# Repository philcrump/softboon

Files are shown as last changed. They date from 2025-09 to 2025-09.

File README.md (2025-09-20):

# SoftBoon

A programmable soft-start board for the Boondocker Dishy Dualie, to ease current surge at start-up.

This project is in no way associated or affiliated with Boondock Energy, Inc.

## Implementation

Small PCB designed for retrofit into an existing project.

<p float="center">
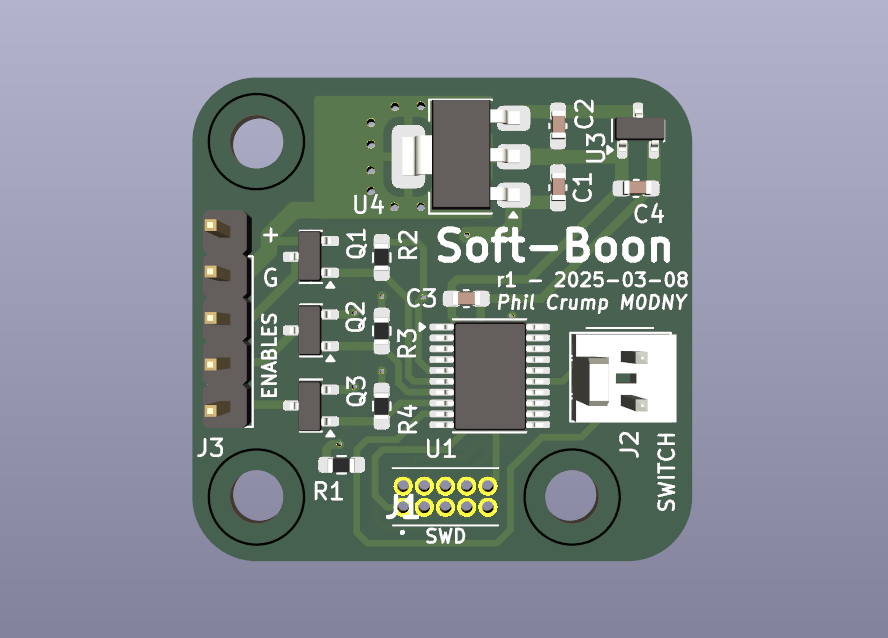
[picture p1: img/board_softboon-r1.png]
  
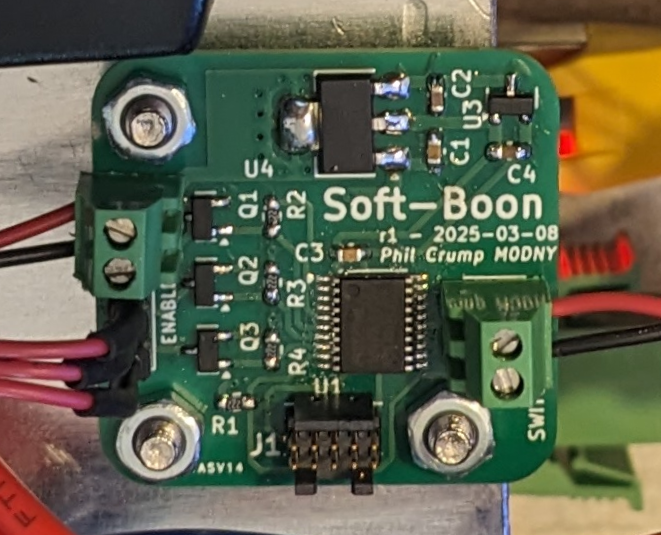
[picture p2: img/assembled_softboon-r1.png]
  
</p>

Schematic: [img/schematic_softboon-r1.pdf](img/schematic_softboon-r1.pdf)

Dual voltage regulators allow use of 7-35V on input (Boondocker is 10-30V).

An STM32F030K6 programmable microcontroller generates the timing logic as follows:

At initial power-on:
* DC-DC and all outputs off.

When the mechanical switch input is On (open)
* Wait 1 second
* Switch the DC-DC on.
* Wait 1 second
* Switch the Dishy PoE on (and Aux Output.)
* Wait 1 second
* Switch the Router PoE on.

When the mechanical switch is Off (closed)
* Immediately switch all outputs and DC-DC off.

### Board Connections

5-pin Header J3:
* "+" (Positive Supply): Recommended to be connected after Fuse and Diode arrangement on the input of the Boondocker to benefit from Reverse Polarity protection. Can tolerate 7-35V.
* "G" (Common/Ground): "Common" on the Dishy Dualie "Remote Shutdown" header.
* Enable 0: "Router Switch" on the Dishy Dualie "Remote Shutdown" header." Can tolerate 45V open, 500mA short.
* Enable 1: "DC-DC Switch" on the Dishy Dualie "Remote Shutdown" header." Can tolerate 45V open, 500mA short.
* Enable 2: "Dishy Switch" on the Dishy Dualie "Remote Shutdown" header." Can tolerate 45V open, 500mA short.

2-pin Header J2:
* Short pins to switch unit off (optional, leave disconnected for always-on). 3.3V @ 1.1mA when shorted.

### Firmware

Written in Rust using the Embassy Framework.

NB: Optimisation and LTO is required to fit the Flash of the microcontroller.

#### Inputs

* PA3 - Switch, 3.3V open, 1.5mA closed.

#### Outputs

* PA0 - Q1 Transistor - Router Switch
* PA1 - Q2 Transistor - DC-DC
* PA2 - Q3 Transistor - Dishy

## Authors

* Phil Crump <phil@philcrump.co.uk>

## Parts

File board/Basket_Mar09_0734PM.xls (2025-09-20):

SHOPPING BASKET
This is not an invoice
09-Mar-25 19:34:48
 | Mouser No | Mfr. No | Manufacturer | Customer No | Description | RoHS | Lifecycle | Order Qty. | Price (GBP) | Ext.: (GBP)
1 | 511-STM32F030F4P6 | STM32F030F4P6 | STMicroelectronics |  | ARM Microcontrollers - MCU Value-Line ARM MCU 16kB 48 MHz | RoHS Compliant |  | 2 | £1.20 | £2.40
2 | 200-FTSH10501FDK | FTSH-105-01-F-D-K | Samtec |  | Headers & Wire Housings High Reliability Header Strips, .050" pitch | RoHS Compliant |  | 2 | £1.68 | £3.36
3 | 595-LM7805MPX/NOPB | LM7805MPX/NOPB | Texas Instruments |  | Linear Voltage Regulators 1.5-A 30-V linear voltage regulator 4- A 595-LM7805MP/NOPB | RoHS Compliant |  | 2 | £1.09 | £2.18
4 | 579-MCP1700T3302E/TT | MCP1700T-3302E/TT | Microchip |  | LDO Voltage Regulators 250mA Adj LDO 2% | RoHS Compliant |  | 2 | £0.403 | £0.81
5 | 771-BC817K-40HVL | BC817K-40HVL | Nexperia |  | Bipolar Transistors - BJT BC817K-40H/SOT23/TO-236AB | RoHS Compliant |  | 6 | £0.134 | £0.80
6 | 603-RT0603FRE072K2L | RT0603FRE072K2L | YAGEO |  | Thin Film Resistors - SMD 1/10W 2.2K ohm 1% 50ppm | RoHS Compliant By Exemption |  | 8 | £0.079 | £0.63
7 | 187-CL10A224KB8NNNC | CL10A224KB8NNNC | Samsung Electro-Mechanics |  | Multilayer Ceramic Capacitors MLCC - SMD/SMT 220nF+/-10% 50V X5R 0603 | RoHS Compliant |  | 2 | £0.087 | £0.17
8 | 810-CGA3E1X7R1C105AC | CGA3E1X7R1C105K080AC | TDK |  | Multilayer Ceramic Capacitors MLCC - SMD/SMT CGA 0603 16V 1uF X7R 10% AEC-Q200 | RoHS Compliant |  | 4 | £0.079 | £0.32
9 | 80-C0603C104M4R7411 | C0603C104M4RAC7411 | KEMET |  | Multilayer Ceramic Capacitors MLCC - SMD/SMT 16V 0.1uF X7R 0603 20% | RoHS Compliant |  | 10 | £0.011 | £0.11
By submitting your order you agree to these terms and conditions. (https://www.mouser.co.uk/saleterms) |  |  |  |  |  |  |  |  | Merchandise: | £10.78
Prices are reflected at the date and time shown. |  |  |  |  |  |  |  |  | Delivery Charge: | £12.00

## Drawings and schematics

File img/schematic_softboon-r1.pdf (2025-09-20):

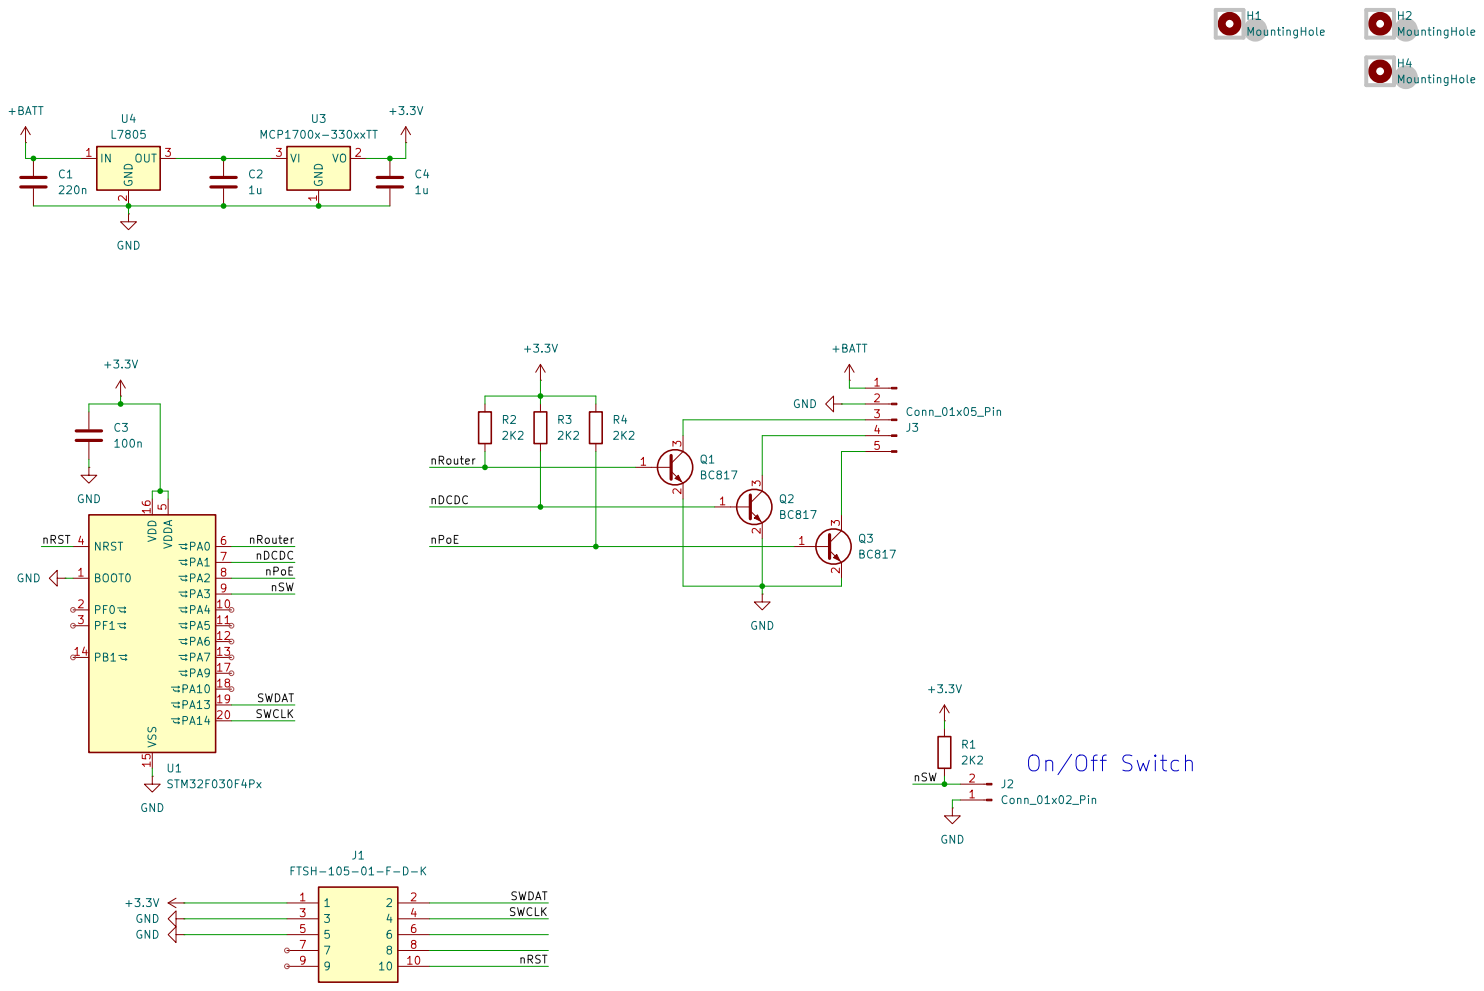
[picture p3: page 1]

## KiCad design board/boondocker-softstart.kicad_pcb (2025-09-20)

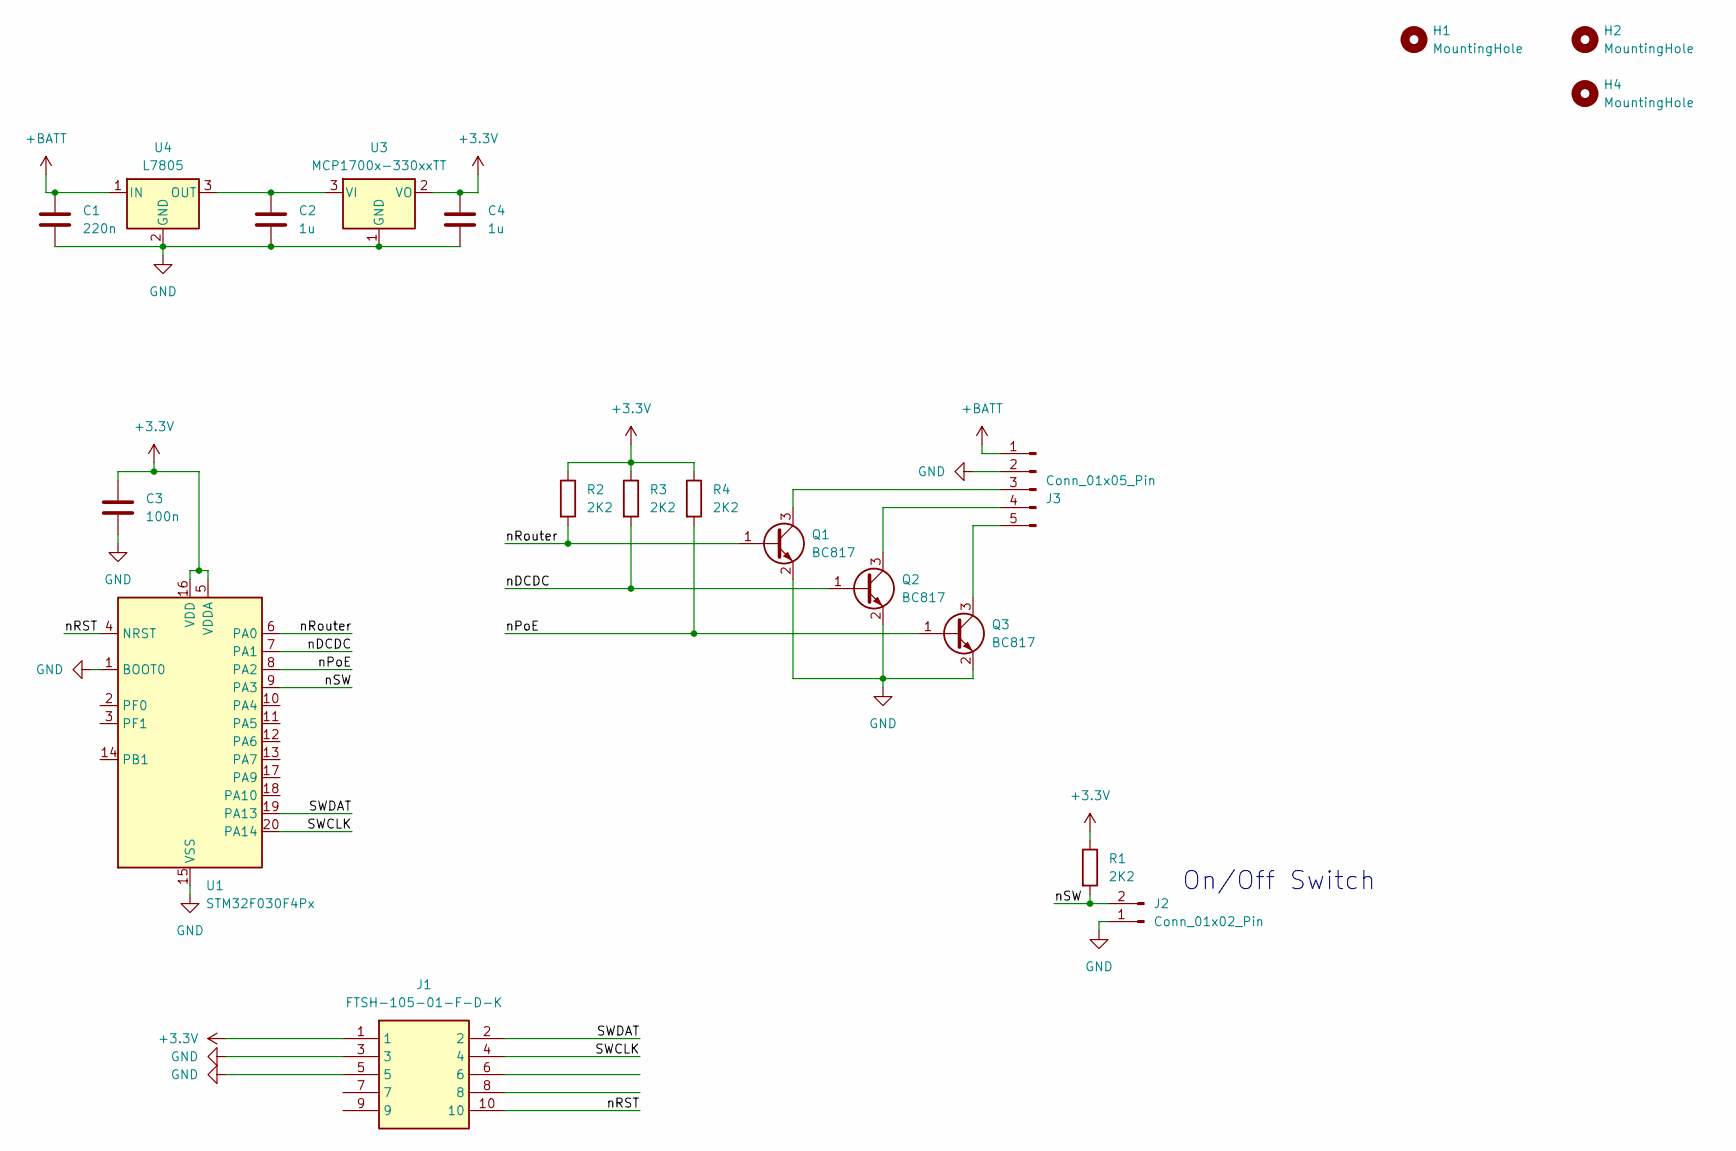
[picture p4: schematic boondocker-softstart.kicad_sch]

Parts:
C1: 220n; C_0603_1608Metric_Pad1.08x0.95mm_HandSolder
C2, C4: 1u; C_0603_1608Metric_Pad1.08x0.95mm_HandSolder
C3: 100n; C_0603_1608Metric_Pad1.08x0.95mm_HandSolder
H1, H2, H4: MountingHole; MountingHole_3.2mm_M3_ISO7380
J1: FTSH-105-01-F-D-K; FTSH-105-XX-YYY-D-K; Mouser Part Number 200-FTSH10501FDK
J2: Conn_01x02_Pin; Molex_KK-254_AE-6410-02A_1x02_P2.54mm_Vertical
J3: Conn_01x05_Pin; PinHeader_1x05_P2.54mm_Vertical
Q1, Q2, Q3: BC817; SOT-23
R1, R2, R3, R4: 2K2; R_0603_1608Metric_Pad0.98x0.95mm_HandSolder
U1: STM32F030F4Px; TSSOP-20_4.4x6.5mm_P0.65mm
U3: MCP1700x-330xxTT; SOT-23
U4: L7805; SOT-223-3_TabPin2

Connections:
+3.3V: C3.1, C4.1, J1.1, R1.1, R2.1, R3.1, R4.1, U1.5 (VDDA), U1.16 (VDD), U3.2 (VO)
+BATT: C1.1, J3.1, U4.1 (IN)
/SWCLK: J1.4, U1.20 (PA14)
/SWDAT: J1.2, U1.19 (PA13)
/nDCDC: Q2.1 (B), R3.2, U1.7 (PA1)
/nPoE: Q3.1 (B), R4.2, U1.8 (PA2)
/nRST: J1.10, U1.4 (NRST)
/nRouter: Q1.1 (B), R2.2, U1.6 (PA0)
/nSW: J2.2, R1.2, U1.9 (PA3)
GND: C1.2, C2.2, C3.2, C4.2, J1.3, J1.5, J2.1, J3.2, Q1.2 (E), Q2.2 (E), Q3.2 (E), U1.1 (BOOT0), U1.15 (VSS), U3.1 (GND), U4.2 (GND)
unnamed: J3.3, Q1.3 (C)
unnamed: J3.4, Q2.3 (C)
unnamed: J3.5, Q3.3 (C)
unnamed: C2.1, U3.3 (VI), U4.3 (OUT)

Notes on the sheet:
On/Off Switch

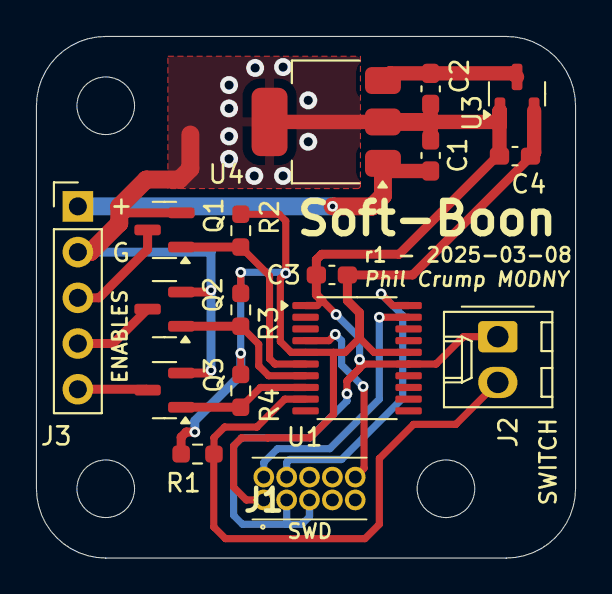
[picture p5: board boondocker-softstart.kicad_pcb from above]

Board: 2 copper layers, 30.0 x 29.0 mm, 20 parts (0 on the bottom side), 14 nets.

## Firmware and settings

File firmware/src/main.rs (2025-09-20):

#![no_std]
#![no_main]

use embassy_executor::Spawner;
use embassy_stm32::wdg::IndependentWatchdog;
use embassy_stm32::gpio::{Level, OutputOpenDrain, Speed, Input, Pull};
use embassy_time::{Instant, Timer};
use {defmt_rtt as _, panic_probe as _};

#[embassy_executor::main]
async fn main(_spawner: Spawner) {
    let p = embassy_stm32::init(Default::default());

    // Initialise outputs as disabled.
    let mut dcdc_disable = OutputOpenDrain::new(p.PA1, Level::High, Speed::Low);
    let mut dishy_disable = OutputOpenDrain::new(p.PA2, Level::High, Speed::Low);
    let mut router_disable = OutputOpenDrain::new(p.PA0, Level::High, Speed::Low);

    // Set up watchdog for 3 second period before reset
    let mut wdg = IndependentWatchdog::new(p.IWDG, 3_000_000);
    wdg.unleash();

    let switch_on = Input::new(p.PA3, Pull::None);

    let mut time_millis:u64 = Instant::now().as_millis();

    let mut state: u32 = 0;
    let mut state_time_millis:u64 = time_millis;

    // Always keep outputs disabled for 1 second at initial power-on
    Timer::after_millis(1000).await;

    loop {
        time_millis = Instant::now().as_millis();

        if switch_on.is_high() {
            if state == 0 {
                dcdc_disable.set_low();

                state = 1;
                state_time_millis = time_millis;
            }
            else if state == 1 && (time_millis - state_time_millis) > 1000 {
                dishy_disable.set_low();

                state = 2;
                state_time_millis = time_millis;
            }
            else if state == 2 && (time_millis - state_time_millis) > 1000 {
                router_disable.set_low();

                state = 3;
                state_time_millis = time_millis;
            }
        }
        else {
            router_disable.set_high();
            dishy_disable.set_high();
            dcdc_disable.set_high();

            state = 0;
            state_time_millis = time_millis;
        }

        Timer::after_millis(10).await;
        wdg.pet();
    }
}
